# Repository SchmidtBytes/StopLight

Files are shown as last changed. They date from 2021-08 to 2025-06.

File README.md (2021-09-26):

# StopLight

This project is a 3D-printable stop light intended as build state indicator.

## 3D model

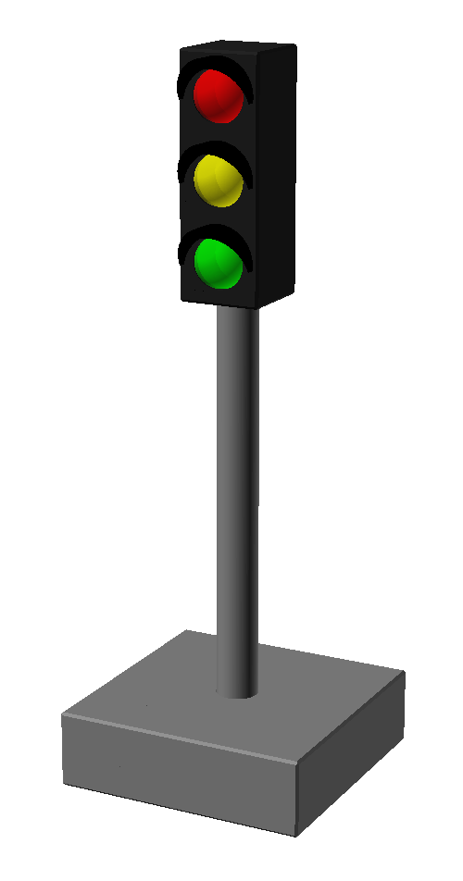
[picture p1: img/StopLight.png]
stop light


The model is created with [OpenSCAD](https://openscad.org/) and is made in a parametric way.

The following model parameters can easily be changed:
- Amount of LEDs
- En/Disable the sun shades above the LEDs
- The inner diameter of the pole for running cables
- The length of the pole
- Making the pole an independent object (allows to print in a different orientation for more stability)

There are also parameters to hide and enable certain parts of the model to simplify the export process.

Additionally there are some visualization tools:
- Show the LEDs in the model
- Show the Arduino Nano
- A cross section of the entire model to view the internal setup

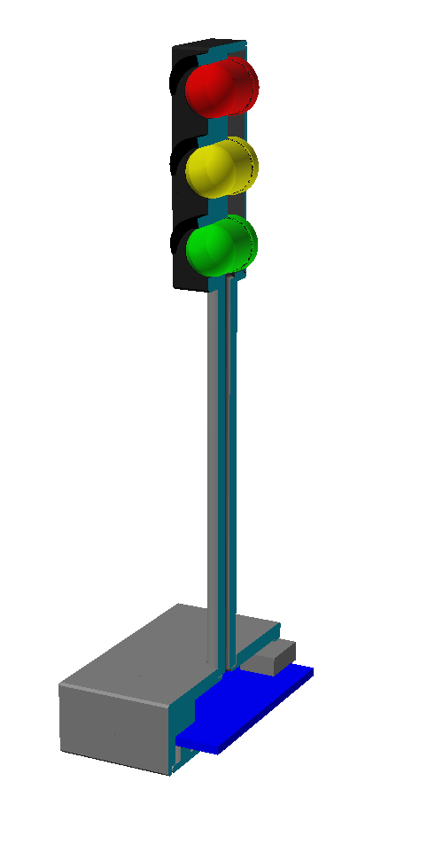
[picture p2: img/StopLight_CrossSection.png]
stop light cross section


## Bill of materials

These things are needed in order to assemble one of these stop lights
- [Arduino Nano](https://store.arduino.cc/products/arduino-nano) or a compatible board as the main brain of the stop lights
- LEDs with 10mm diameter (3 by default in red, yellow and green)
- One 180 Ohms resistor for each of the LEDs

Depending on where you buy these things this will run you about 5 to 20 € for the 3 LED variant.

Additionally you will need a soldering station, solder, some thin wires (preferably thread wire) and the material to 3D print the model.

## Assembly

At first you need to print all the parts for your stop light.

Then start with super gluing the pole to the housing and the base of the stop light.

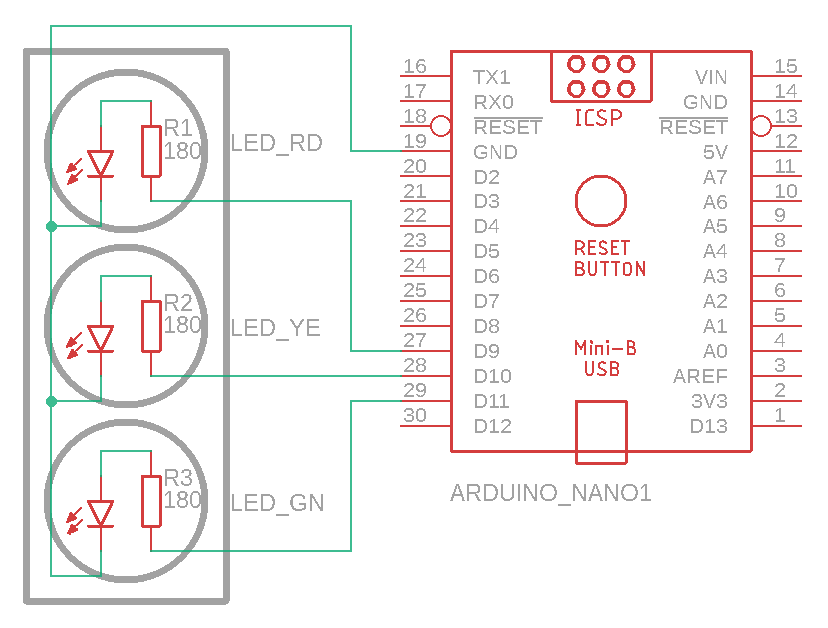
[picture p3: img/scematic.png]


Then add the LEDs from top to bottom. Keep all the cathodes on one side, so you can simply solder them all together and only need a single ground wire from the top to the base. The resistors are best added to the anode pin of the LEDs.

Once all the LEDs are wired and the connected to the Arduino Nano test them once before gluing them in place with super glue and then add the back panel of the stop light.
Then put the Arduino in the base and close the door.

## Software

This section gives insights about the default [StopLight_3](https://github.com/SchmidtBytes/StopLight/blob/main/programs/StopLight_3/StopLight_3.ino) program.
Other programs might add or delete features.

The programs are all written using the [Arduino IDE](https://www.arduino.cc/en/Main/Software_).

### LED usage

The LEDs are connected to the PWM pins of the Arduino so they can be used as digital and analog outputs.
They are wired in a way so that HIGH is LED on and LOW is LED off.

You can either write a digital value by using the digitalWrite command.

```c
digitalWrite(LED_RD, HIGH); // Turn the red LED on
digitalWrite(LED_GN, LOW);  // Turn the green LED off
```

Or you can also use the analogWrite command and set a value between 0 and 255.

```c
analogWrite(LED_YE, 127); // Set the yellow LED to half brightness
```

### Serial interface

The serial interface is connected via the USB port.
By default the baud rate is set to **38400**.
The Arduino will cyclically check for new commands on the serial interface and adapt its internal state machine.

### Commands

The commands are currently one letter codes for the various states.
The state will change if the code is known and the requested state is not already active.

| code | state | description |
|-----:|:---:|:---|
| i | STATE_INIT | Initialization animation |
| o | STATE_OFF | Turn off all of the LEDs |
| b | STATE_BUILDING  | Flash the yellow LED, but dim the transitions |
| s | STATE_SUCCESS | Light up only the green LED |
| u | STATE_UNSTABLE  | Light up only the yellow LED |
| f | STATE_FAILED | Light up only the red LED |
| p | STATE_PREPARE | Light up both yellow and red |
| n | STATE_NIGHT | Flash the yellow light, but with no dimming |
| w | STATE_WAIT | Flash the red and green LEDs at the same time |
| a | STATE_ALTERNATE | Alternate between yellow and the other LEDs |
| r | STATE_ROLLING | Rolling animation from red to green |
| c | STATE_CYCLE | Run a normal stop light animation |
| e | | Enable the sleep mode feature. This will be saved over power cycles  |
| d | | Disable the sleep mode feature. This will be saved over power cycles |

The stop light will accept the state codes both in upper and lower case letters.

### Sleep mode

Sleep mode is a feature to turn off the stop light LEDs after a certain amount of time has passed.
After this the stop light will automatically switch to **STATE_OFF**, but will continue to listen for commands.
By default this is set to 1 hour after receiving the last command.

### Libraries

As of now no external libraries are needed.

## Usage

The usage of the stop light is rather simple.
All typical operating systems come with the necessary drivers.
First you need to set the right baud rate to the serial interface (38400 by default).
In order to set the state just write the letter for the desired state to the serial interface.

From the Linux shell you can simply set the state with this command:

``` shell
echo s > /dev/ttyUSB0
```

## Contribution

Feel free to share and upload your own ideas and features.

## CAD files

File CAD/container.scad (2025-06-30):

use <StopLight.scad>

MATERIAL_THICKNESS = 1;
TOTAL_HEIGHT = 139;
MARGIN = .7;
BEND_LENGTH = (MARGIN + (MATERIAL_THICKNESS/2)) * PI/2;
echo("Bend length:", BEND_LENGTH);

/* [Global resolution] */
// Minimal facet size
$fs = 0.1;  // [0.1:0.01:10]
// Minimal angle size
$fa = 1;    // [1:0.1:90]

rotate([-90,0,0])translate([0,-25,95-(TOTAL_HEIGHT/2)])union() {
    housing(shades=true, lights=3);
    housing_back(3);
    pole(80);
    base_door();
}

//#translate([0,0,25])cube([50,TOTAL_HEIGHT,50],center=true);

translate([0,0,-(MATERIAL_THICKNESS/2)-MARGIN])cube([50,TOTAL_HEIGHT+(4*MARGIN)+(2*MATERIAL_THICKNESS),MATERIAL_THICKNESS],center=true);

translate([25,0,0])rotate([-90,0,0])rotate_extrude(angle = 90)translate([MARGIN+(MATERIAL_THICKNESS/2),0])square([MATERIAL_THICKNESS,TOTAL_HEIGHT+2*MARGIN+MATERIAL_THICKNESS],center=true);
translate([-25,0,0])rotate([-90,0,180])rotate_extrude(angle = 90)translate([MARGIN+(MATERIAL_THICKNESS/2),0])square([MATERIAL_THICKNESS,TOTAL_HEIGHT+2*MARGIN+MATERIAL_THICKNESS],center=true);

translate([(MATERIAL_THICKNESS/2)+MARGIN+25,0,25])cube([MATERIAL_THICKNESS,TOTAL_HEIGHT+2*MARGIN+MATERIAL_THICKNESS,50],center=true);
translate([-25-(MATERIAL_THICKNESS/2)-MARGIN,0,25])cube([MATERIAL_THICKNESS,TOTAL_HEIGHT+2*MARGIN+MATERIAL_THICKNESS,50],center=true);

translate([0,(TOTAL_HEIGHT/2)+(2*MARGIN)+MATERIAL_THICKNESS,0])rotate([-90,0,90])rotate_extrude(angle = 90)translate([MARGIN+(MATERIAL_THICKNESS/2),0])square([MATERIAL_THICKNESS,50],center=true);
translate([0,-(TOTAL_HEIGHT/2)-(2*MARGIN)-MATERIAL_THICKNESS,0])rotate([-90,0,-90])rotate_extrude(angle = 90)translate([MARGIN+(MATERIAL_THICKNESS/2),0])square([MATERIAL_THICKNESS,50],center=true);

translate([0,(TOTAL_HEIGHT/2)+MARGIN+(MATERIAL_THICKNESS/2),24])cube([50,MATERIAL_THICKNESS,48],center=true);
translate([0,-(TOTAL_HEIGHT/2)-MARGIN-(MATERIAL_THICKNESS/2),24])cube([50,MATERIAL_THICKNESS,48],center=true);
translate([0,(TOTAL_HEIGHT/2)+(MARGIN*3)+(1.5*MATERIAL_THICKNESS),24])cube([50,MATERIAL_THICKNESS,48],center=true);
translate([0,-(TOTAL_HEIGHT/2)-(MARGIN*3)-(1.5*MATERIAL_THICKNESS),24])cube([50,MATERIAL_THICKNESS,48],center=true);

translate([0,(TOTAL_HEIGHT/2)+(2*MARGIN)+MATERIAL_THICKNESS,48])rotate([90,0,90])rotate_extrude(angle = 180)translate([MARGIN+(MATERIAL_THICKNESS/2),0])square([MATERIAL_THICKNESS,50],center=true);
translate([0,-(TOTAL_HEIGHT/2)-(2*MARGIN)-MATERIAL_THICKNESS,48])rotate([90,0,-90])rotate_extrude(angle = 180)translate([MARGIN+(MATERIAL_THICKNESS/2),0])square([MATERIAL_THICKNESS,50],center=true);

translate([13,(TOTAL_HEIGHT/2)+(2*MARGIN)+(MATERIAL_THICKNESS),24])cube([24,MATERIAL_THICKNESS,48],center=true);
translate([-13,(TOTAL_HEIGHT/2)+(2*MARGIN)+(MATERIAL_THICKNESS),24])cube([24,MATERIAL_THICKNESS,48],center=true);
translate([13,-(TOTAL_HEIGHT/2)-(2*MARGIN)-(MATERIAL_THICKNESS),24])cube([24,MATERIAL_THICKNESS,48],center=true);
translate([-13,-(TOTAL_HEIGHT/2)-(2*MARGIN)-(MATERIAL_THICKNESS),24])cube([24,MATERIAL_THICKNESS,48],center=true);

translate([25,(TOTAL_HEIGHT/2)+(MARGIN)+(MATERIAL_THICKNESS/2),24])rotate([0,0,0])rotate_extrude(angle = 90)translate([MARGIN+(MATERIAL_THICKNESS/2),0])square([MATERIAL_THICKNESS,48],center=true);
translate([-25,(TOTAL_HEIGHT/2)+(MARGIN)+(MATERIAL_THICKNESS/2),24])rotate([0,0,90])rotate_extrude(angle = 90)translate([MARGIN+(MATERIAL_THICKNESS/2),0])square([MATERIAL_THICKNESS,48],center=true);
translate([25,-(TOTAL_HEIGHT/2)-(MARGIN)-(MATERIAL_THICKNESS/2),24])rotate([0,0,-90])rotate_extrude(angle = 90)translate([MARGIN+(MATERIAL_THICKNESS/2),0])square([MATERIAL_THICKNESS,48],center=true);
translate([-25,-(TOTAL_HEIGHT/2)-(MARGIN)-(MATERIAL_THICKNESS/2),24])rotate([0,0,180])rotate_extrude(angle = 90)translate([MARGIN+(MATERIAL_THICKNESS/2),0])square([MATERIAL_THICKNESS,48],center=true);

translate([-25,0,50])rotate([-90,-90,180])rotate_extrude(angle = 90)translate([MARGIN+(MATERIAL_THICKNESS/2),0])square([MATERIAL_THICKNESS,TOTAL_HEIGHT+2*MARGIN+MATERIAL_THICKNESS],center=true);
translate([25+(MARGIN)+(MATERIAL_THICKNESS/2),0,50])rotate([-90,-90,0])rotate_extrude(angle = 90)translate([MARGIN+(MATERIAL_THICKNESS/2),0])square([MATERIAL_THICKNESS,TOTAL_HEIGHT+2*MARGIN+MATERIAL_THICKNESS],center=true);

translate([(MARGIN/2)+(MATERIAL_THICKNESS/4),0,50+(MATERIAL_THICKNESS/2)+MARGIN])cube([50+MARGIN+(MATERIAL_THICKNESS/2),TOTAL_HEIGHT+2*MARGIN+MATERIAL_THICKNESS,MATERIAL_THICKNESS],center=true);
intersection() {
    translate([(MATERIAL_THICKNESS)+(MARGIN*2)+25,0,25])cube([MATERIAL_THICKNESS,TOTAL_HEIGHT+2*MARGIN+MATERIAL_THICKNESS,50],center=true);
    hull(){
        translate([(MATERIAL_THICKNESS)+(MARGIN*2)+25,(TOTAL_HEIGHT/2)-20+MARGIN+(MATERIAL_THICKNESS/2),50])rotate([0,90,0])cylinder(r=20,h=2*MATERIAL_THICKNESS,center=true);
        translate([(MATERIAL_THICKNESS)+(MARGIN*2)+25,-(TOTAL_HEIGHT/2)+20-MARGIN-(MATERIAL_THICKNESS/2),50])rotate([0,90,0])cylinder(r=20,h=2*MATERIAL_THICKNESS,center=true);
        translate([(MATERIAL_THICKNESS)+(MARGIN*2)+25,0,20])rotate([0,90,0])cylinder(r=20,h=2*MATERIAL_THICKNESS,center=true);
    }
}

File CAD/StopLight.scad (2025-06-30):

/* [Customization] */
// Ammount of LEDs for the stop light
NUM_LIGHTS       = 3; // [20]
// Add or remove the sunshades
SHADES           = true;
// The length of the stop light pole
POLE_LENGTH      = 80; // [2:0.01:200]
// Make the pole a separate object
INDEPENDENT_POLE = true;
// The inner diameter of the pole
POLE_DI          = 2; // [0:0.01:8]
// The controller used in the stop light
VARIANT             = "Arduino Nano"; // ["Arduino Nano", "ESP32-C6 Supermini"]
// The locking mechanism attaching the base door to the base
BASE_LOCK           = "Clip"; // ["Clip", "Screw"]

/* [Enable/Disable parts] */
// Show the LED housing
ENABLE_LED_HOUSING = true;
// Show the back of the LED housing
ENABLE_BACK_PANEL  = true;
// Show the pole
ENABLE_POLE        = true;
// Show the pole base
ENABLE_BASE        = true;
// Show the base door
ENABLE_BASE_DOOR   = true;

/* [Cosmetic options] */
// Show the LEDs
SHOW_LEDs        = false;
// Show the Arduino
SHOW_CONTROLLER  = false;
// Show a cross section of the stop light
CROSS_SECTION    = false;
// The angle to cut the cross section at
CROSS_SECTION_ANGLE = 0; // [-90:45:90]

/* [Global resolution] */
// Minimal facet size
$fs = 0.1;  // [0.1:0.01:10]
// Minimal angle size
$fa = 1;    // [1:0.1:90]


if(SHOW_LEDs) {
    if(NUM_LIGHTS > 1)
        translate([0,0,6+(15*(NUM_LIGHTS-1))])LED("#ff000080");
    if(NUM_LIGHTS > 2) {
        for(i=[0:NUM_LIGHTS-3]) {
            translate([0,0,6+(15*(i+1))])LED("#ffff0080");
        }
    }
    translate([0,0,6])LED("#00ff0080");
}

if(SHOW_CONTROLLER && VARIANT == "Arduino Nano") {
    translate([0,1.75,-POLE_LENGTH-8.5])arduino_nano();
}
if(SHOW_CONTROLLER && VARIANT == "ESP32-C6 Supermini") {
    translate([0,11.8,-POLE_LENGTH-8.5])ESP32_C3_SuperMini();
}

difference() {
    union() {
        if(ENABLE_LED_HOUSING) {
            housing(shades=SHADES, lights=NUM_LIGHTS);
        }
        if(ENABLE_BACK_PANEL) {
            housing_back(lights=NUM_LIGHTS);
        }
        pole(POLE_LENGTH);
        if(ENABLE_BASE_DOOR) {
            base_door();
        }
    }
    if(CROSS_SECTION) {
        rotate([0,0,CROSS_SECTION_ANGLE])translate([0,-40,-POLE_LENGTH-30])cube([50,80,40+(15*NUM_LIGHTS)+POLE_LENGTH]);
    }
}

module LED(col="") {
    color(col) union() {
        translate([0,0.5,0])rotate([90,0,0])cylinder(d=10,h=7);
        rotate([-90,0,0])cylinder(d=11,h=2);
        translate([0,-6.5,0])sphere(d=10);
    }
}

module housing_back(lights = 3) {
    box_height = 16 + ((lights-1)*15);
    color("#404040")translate([0,7.5,(box_height/2)-2])
    slanted_cube(16-2.2,1,box_height-2.2);
    color("#404040")translate([0,7.75,(box_height/2)-2])
    cube([16-2.2,0.5,box_height-2.2],center=true);
}

module housing(shades=false,lights = 3) {
    box_height = 16 + ((lights-1)*15);
    color("#202020")translate([0,0,(box_height/2)-2])difference() {
        // main body
        slanted_cube(16,16,box_height);

        for(i=[0:lights-1]) {
            // LEDs
            translate([0,0,((15*(lights-1))/2)-(15*i)])rotate([90,0,0])linear_extrude(height=8.01,scale=0.95)circle(d=10.6);
            translate([0,-0.20,((15*(lights-1))/2)-(15*i)])rotate([-90,0,0])cylinder(d=12.5,h=10);
        }

        // remove interior
        translate([0,7.8,0])cube([10,16,box_height-6],center=true);
        translate([0,14.8,0])cube([14,16,box_height-2],center=true);

        // pole
        translate([0,0,(-box_height/2)+2])cylinder(d=2,h=5,center=true);
        translate([0,0,(-box_height/2)-1])cylinder(d=6.2,h=6,center=true);
    }

    // shields
    if(shades) {
        for(j=[0:lights-1]) {
            color("#000000")translate([0,0,(box_height/2)-2])difference () {
                translate([0,-7,((15*(lights-1))/2)-(15*j)+0.1])rotate([90,0,0])cylinder(d=14,h=6);
                translate([0,-6.5,((15*(lights-1))/2)-(15*j)-1.9])rotate([90,0,0])cylinder(d=14,h=7);
                translate([0,-10,((15*(lights-1))/2)-(15*j)])rotate([110,0,0])cylinder(d=17,h=7);
            }
        }
    }
}

module pole(length=70) {
    if(ENABLE_POLE) {
        color("gray")translate([0,0,-length/2])difference() {
            union() {
                cylinder(d=6,h=length,center=true);
                if(INDEPENDENT_POLE) {
                    translate([0,0,-2])cylinder(d=8,h=length,center=true);
                } else {
                    translate([0,0,-1])cylinder(d=8,h=length-2,center=true);
                }
            }
            cylinder(d=POLE_DI,h=length+10,center=true);
            translate([0,0,length/2])rotate([-90,0,0])cylinder(d=2,h=6);
        }
    }

    if(ENABLE_BASE){
        translate([0,0,-length])base();
    }
}

module base_door() {
    color("gray")translate([0,0,-15-POLE_LENGTH]) difference() {
        union() {
            difference() {
                union() {
                    translate([0,0,0.75])slanted_cube(46.6,46.6,1.5);
                    if(BASE_LOCK == "Clip") {
                        translate([-20,0,4])rotate([90,0,0])cylinder(d=3.6, h=20,center=true);
                    }
                    if(BASE_LOCK == "Screw") {
                        translate([-17,0,2.5])cylinder(d1=10.8,d2=8.8,h=2,center=true);
                    }
                }
                if(BASE_LOCK == "Clip") {
                    translate([-21.5,0,0.9])cube([15,22,2],center=true);
                    translate([-17,0,0.9])cube([4,21,10],center=true);
                }
                if(BASE_LOCK == "Screw") {
                    translate([-17,0,-2])cylinder(d=3.2,h=15,center=true);
                    translate([-17,0,.99])cylinder(d2=3.2,d1=6.4,h=2,center=true);
                }
            }
            if(BASE_LOCK == "Clip") {
                translate([-8,0,0]) difference() {
                    rotate([90,0,0])cylinder(d=26, h=20,center=true);
                    rotate([90,0,0])cylinder(d=22, h=21,center=true);
                    translate([0,0,-10])cube([50,50,20],center=true);
                    translate([21,0,8])cube([50,50,20],center=true);
                }
                translate([-13,0,5.5])cube([2,20,11],center=true);
            }
            translate([15.8,-10,5])rotate([90,0,0])linear_extrude(height=10)polygon([[0,-5],[5,1],[7,1],[7,-0.3],[5,-0.8],[5,-5]]);
            translate([15.8,20,5])rotate([90,0,0])linear_extrude(height=10)polygon([[0,-5],[5,1],[7,1],[7,-0.3],[5,-0.8],[5,-5]]);
            if(BASE_LOCK == "Clip") {
                translate([0,-18,0])cylinder(d=4,h=5.4);
            }
            if(BASE_LOCK == "Screw") {
                translate([-7,2,0])cylinder(d=4,h=5.95);
                translate([7,2,0])cylinder(d=4,h=5.95);
            }
        }
        if(BASE_LOCK == "Clip") {
            translate([-11.5,0,12])rotate([0,45,0])cube([3,22,3],center=true);
        }
    }
}

module base() {
    color("gray")translate([0,0,-7.5])difference() {
        slanted_cube(50,50,15);
        translate([0,0,3.8])linear_extrude(height=6,scale=0)circle(d=5);
        translate([0,0,-13.3])cube([47,47,15],center=true);
        translate([0,0,-5+2])cube([20,44,15],center=true);
        translate([16,0,-5+4])cube([10,44,15],center=true);
        translate([18,0,-5+4+2.5])cube([10,44,10],center=true);
        if(BASE_LOCK == "Clip") {
            translate([-16,0,-5+4])cube([10,44,15],center=true);
            translate([-20,0,-6.5+3])rotate([90,0,0])cylinder(d=4, h=22,center=true);
        }
        else if(BASE_LOCK == "Screw") {
            translate([-17,0,-2])cylinder(d=4.1,h=15,center=true);
            translate([-17,0,-4.81])cylinder(d1=11,d2=9,h=2,center=true);
        }
        cylinder(d=POLE_DI, h=16);
        if(INDEPENDENT_POLE) {
            translate([0,0,5.3])cylinder(d=8.3, h=16);
        }
        if(VARIANT == "Arduino Nano") {
            translate([0,1.75,-10.5+7.5+2])arduino_nano();
        }
        else if(VARIANT == "ESP32-C6 Supermini") {
            translate([0,11.8,-10.5+7.5+2])ESP32_C3_SuperMini();
        }
    }
    if(VARIANT == "Arduino Nano") {
        color("gray")difference() {
            translate([0,-19,-5])cube([10,10,8],center=true);
            translate([0,1.75,-10.5+2])arduino_nano();
        }
    }
    else if(VARIANT == "ESP32-C6 Supermini") {
        color("gray")difference() {
            union() {
                translate([-10,0,-9])cylinder(d=5, h=8);
                translate([10,0,-9])cylinder(d=5, h=8);
            }
            translate([0,11.8,-10.5+2])ESP32_C3_SuperMini();
            translate([13.5,0,-6])cube([6,6,10],center=true);
        }
    }
}

module ESP32_C3_SuperMini() {
    color("blue")translate([0,-.25,0])cube([18.3,23.2,1.1],center=true);
    color("#404040")translate([0,5.75,1.1/2])rotate([-90,0,0])hull() {
        translate([(8.9-3.1)/2,-3.1/2,0])cylinder(d=3.4, h=7.5);
        translate([-(8.9-3.1)/2,-3.1/2,0])cylinder(d=3.4, h=7.5);
    }
    color("#202020")translate([-5.8,10,2.1/2])cube([2.75,3,1],center=true);
}
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

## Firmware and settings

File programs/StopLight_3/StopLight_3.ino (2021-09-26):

/*
  Build status stop light code
  V 1.0
*/

#include <EEPROM.h>

// LED Pin definitions
#define LED_RD 9
#define LED_YE 10
#define LED_GN 11

// Serial speed definition
#define SERIAL_SPEED 38400

// Non state commands:
// code: e; Enables the sleep mode feature (default: enabled)
//          WARNING this setting will be persisted and will not reset when turning the device off
// code: d; Disables the sleep mode feature (default: enabled)
//          WARNING this setting will be persisted and will not reset when turning the device off

// stop light state definitions
#define STATE_INIT       0 // code: i; Initialization animation
#define STATE_OFF        1 // code: o; Turn off all of the LEDs
#define STATE_BUILDING   2 // code: b; Flash the yellow LED, but dim the transitions
#define STATE_SUCCESS    3 // code: s; Light up only the green LED
#define STATE_UNSTABLE   4 // code: u; Light up only the yellow LED
#define STATE_FAILED     5 // code: f; Light up only the red LED
#define STATE_PREPARE    6 // code: p; Light up both yellow and red
#define STATE_NIGHT      7 // code: n; Flash the yellow light, but with no dimming
#define STATE_WAIT       8 // code: w; Flash the red and green LEDs at the same time
#define STATE_ALTERNATE  9 // code: a; Alternate between yellow and the other LEDs
#define STATE_ROLLING   10 // code: r; Rolling animation from red to green
#define STATE_CYCLE     98 // code: c; Run a normal stop light animation
#define STATE_PARTY     99 // code: $; Flash the LEDs at random times and brightness levels

// Timing
#define CYCLE_TIME      10 // [ms] Time to wait in between cycles
#define TURN_OFF_TIME   ((uint32_t) 3600/*[s/h]*/ * 1000/*[ms/s]*/ / CYCLE_TIME/*[ms/cycle]*/)
                        // Number of cycles before turning the stop light off
                        // (default: Turn off after 1 hour)

#define SLEEP_STATE_ADDR 0x000 // Location of the sleep state in the EEPROM that is read on start

int incoming_byte = 0;                  // for incoming serial data
int state = 0;                          // memory for the currently active state
bool sleep_active = true;               // Holds the current state if sleep mode is active
uint32_t sleep_timer = TURN_OFF_TIME;   // counter to enable sleep mode
unsigned long next_cycle = CYCLE_TIME;  // time when to start with the next cycle
unsigned long time_mili = 0;            // Current system time in miliseconds
int state_var = 0;                      // variable that can be used by the currently active state to save some information
                                        // This is mostly used to time the flash patterns for repeating states
uint32_t change_time_r = TURN_OFF_TIME; // Variable to save when to change the red LED; only used in some states
uint32_t change_time_y = TURN_OFF_TIME; // Variable to save when to change the yellow LED; only used in some states
uint32_t change_time_g = TURN_OFF_TIME; // Variable to save when to change the green LED; only used in some states

// the setup function runs once when you press reset or power the board
void setup() {
  // initialize the serial interface
  Serial.begin(SERIAL_SPEED);

  // setup the pins of the leds
  pinMode(LED_RD, OUTPUT);
  pinMode(LED_YE, OUTPUT);
  pinMode(LED_GN, OUTPUT);

  // read from an unconnected analog input to initialize the random function
  randomSeed(analogRead(0));

  // initialize sleep_active from EEPROM
  incoming_byte = EEPROM.read(SLEEP_STATE_ADDR);
  if(incoming_byte > 1) {
    // Initialize the EEPROM with true if the value is not valid
    EEPROM.write(SLEEP_STATE_ADDR, true);
    incoming_byte = 1;
  }
  sleep_active = incoming_byte;
}

// the loop function runs over and over again forever
void loop() {
  if (Serial.available() > 0) {
    // read a byte from the serial interface
    incoming_byte = Serial.read();
    // convert to lower case
    if (incoming_byte >= 'A' && incoming_byte <= 'Z')
        incoming_byte += 'a' - 'A';

    bool byte_accepted = true;
    // Check none state commands
    if(incoming_byte == 'd'){
        sleep_active = false;
        EEPROM.write(SLEEP_STATE_ADDR, sleep_active);
        digitalWrite(LED_YE, LOW);
        digitalWrite(LED_GN, LOW);
        for(uint8_t ctr = 0; ctr < 8; ctr++) {
            digitalWrite(LED_RD, (ctr + 1)%2);
            delay(125);
        }
    }
    else if(incoming_byte == 'e') {
        sleep_active = true;
        EEPROM.write(SLEEP_STATE_ADDR, sleep_active);
        digitalWrite(LED_RD, LOW);
        digitalWrite(LED_YE, LOW);
        for(uint8_t ctr = 0; ctr < 8; ctr++) {
            digitalWrite(LED_GN, (ctr + 1)%2);
            delay(125);
        }
    }

    // Check which state was requested and set it up if necessary
    if(incoming_byte == 'i' && state != STATE_INIT)
      state = STATE_INIT;
    else if(incoming_byte == 'o' && state != STATE_OFF)
      state = STATE_OFF;
    else if(incoming_byte == 'b' && state != STATE_BUILDING)
      state = STATE_BUILDING;
    else if(incoming_byte == 's' && state != STATE_SUCCESS)
      state = STATE_SUCCESS;
    else if(incoming_byte == 'u' && state != STATE_UNSTABLE)
      state = STATE_UNSTABLE;
    else if(incoming_byte == 'f' && state != STATE_FAILED)
      state = STATE_FAILED;
    else if(incoming_byte == 'p' && state != STATE_PREPARE)
      state = STATE_PREPARE;
    else if(incoming_byte == 'n' && state != STATE_NIGHT)
      state = STATE_NIGHT;
    else if(incoming_byte == 'w' && state != STATE_WAIT)
      state = STATE_WAIT;
    else if(incoming_byte == 'a' && state != STATE_ALTERNATE)
      state = STATE_ALTERNATE;
    else if(incoming_byte == 'r' && state != STATE_ROLLING)
      state = STATE_ROLLING;
    else if(incoming_byte == 'c' && state != STATE_CYCLE)
      state = STATE_CYCLE;
    else if(incoming_byte == '$' && state != STATE_PARTY)
    {
      state = STATE_PARTY;
      change_time_r = TURN_OFF_TIME;
      change_time_y = TURN_OFF_TIME;
      change_time_g = TURN_OFF_TIME;
    }
    else
      // detect if requested state is already active or state code was invalid
      byte_accepted = false;

    if(byte_accepted)
        // Reset the state var for the new state
        state_var=0;
    else if(state == STATE_PARTY)
    {
        uint32_t diff_time = TURN_OFF_TIME - sleep_timer;
        change_time_r += diff_time;
        change_time_y += diff_time;
        change_time_g += diff_time;
    }

    // reset the sleep timer
    sleep_timer = TURN_OFF_TIME;
  }

  // State machine for the various states
  switch(state){
    case STATE_INIT:
      if (state_var < (500/*ms*/ / CYCLE_TIME)) {
        analogWrite(LED_RD, (255 * (state_var % (500/*ms*/ / CYCLE_TIME))) / (500/*ms*/ / CYCLE_TIME));
        digitalWrite(LED_YE, LOW);
        digitalWrite(LED_GN, LOW);
      }
      else if(state_var < (1000/*ms*/ / CYCLE_TIME)) {
        digitalWrite(LED_RD, HIGH);
        analogWrite(LED_YE, (255 * (state_var % (500/*ms*/ / CYCLE_TIME))) / (500/*ms*/ / CYCLE_TIME));
        digitalWrite(LED_GN, LOW);
      }
      else if(state_var < (1500/*ms*/ / CYCLE_TIME)) {
        digitalWrite(LED_RD, HIGH);
        digitalWrite(LED_YE, HIGH);
        analogWrite(LED_GN, (255 * (state_var % (500/*ms*/ / CYCLE_TIME))) / (500/*ms*/ / CYCLE_TIME));
      }
      else if(state_var < (3000/*ms*/ / CYCLE_TIME)) {
        digitalWrite(LED_RD, HIGH);
        digitalWrite(LED_YE, HIGH);
        digitalWrite(LED_GN, HIGH);
      }
      else if(state_var < (3500/*ms*/ / CYCLE_TIME)) {
        analogWrite(LED_RD, 255 - ((255 * (state_var % (500/*ms*/ / CYCLE_TIME))) / (500/*ms*/ / CYCLE_TIME)));
        digitalWrite(LED_YE, HIGH);
        digitalWrite(LED_GN, HIGH);
      }
      else if(state_var < (4000/*ms*/ / CYCLE_TIME)) {
        digitalWrite(LED_RD, LOW);
        analogWrite(LED_YE, 255 - ((255 * (state_var % (500/*ms*/ / CYCLE_TIME))) / (500/*ms*/ / CYCLE_TIME)));
        digitalWrite(LED_GN, HIGH);
      }
      else if(state_var < (4500/*ms*/ / CYCLE_TIME)) {
        digitalWrite(LED_RD, LOW);
        digitalWrite(LED_YE, LOW);
        analogWrite(LED_GN, 255 - ((255 * (state_var % (500/*ms*/ / CYCLE_TIME))) / (500/*ms*/ / CYCLE_TIME)));
      }
      else {
        // Automatically switch to off state after finishing the initialization animation
        state = STATE_OFF;
        sleep_timer = 0;
      }
      // increase the state var to run through the animation
      state_var ++;
      break;

    case STATE_OFF:
      digitalWrite(LED_RD, LOW);
      digitalWrite(LED_YE, LOW);
      digitalWrite(LED_GN, LOW);
      break;

    case STATE_BUILDING:
      digitalWrite(LED_RD, LOW);
      if(state_var < (500/*ms*/ / CYCLE_TIME))
        analogWrite(LED_YE, (255 * state_var) / (500/*ms*/ / CYCLE_TIME));
      else if(state_var < (750/*ms*/ / CYCLE_TIME))
      {
        digitalWrite(LED_YE, HIGH);
      }
      else if(state_var < (1250/*ms*/ / CYCLE_TIME))
        analogWrite(LED_YE, 255 - ((255 * (state_var - (750 / CYCLE_TIME))) / (500/*ms*/ / CYCLE_TIME)));
      else
        digitalWrite(LED_YE, LOW);
      digitalWrite(LED_GN, LOW);
      // increase the state_var to run through the animation
      state_var = (state_var + 1) % (1500/*ms*/ / CYCLE_TIME);
      break;

    case STATE_SUCCESS:
      digitalWrite(LED_RD, LOW);
      digitalWrite(LED_YE, LOW);
      digitalWrite(LED_GN, HIGH);
      break;

    case STATE_UNSTABLE:
      digitalWrite(LED_RD, LOW);
      digitalWrite(LED_YE, HIGH);
      digitalWrite(LED_GN, LOW);
      break;

    case STATE_FAILED:
      digitalWrite(LED_RD, HIGH);
      digitalWrite(LED_YE, LOW);
      digitalWrite(LED_GN, LOW);
      break;

    case STATE_PREPARE:
      digitalWrite(LED_RD, HIGH);
      digitalWrite(LED_YE, HIGH);
      digitalWrite(LED_GN, LOW);
      break;

    case STATE_NIGHT:
      digitalWrite(LED_RD, LOW);
      digitalWrite(LED_YE, state_var<(1000/*ms*/ / CYCLE_TIME)?HIGH:LOW);
      digitalWrite(LED_GN, LOW);
      // increase the state_var to run through the animation
      state_var = (state_var + 1) % (2000/*ms*/ / CYCLE_TIME);
      break;

    case STATE_WAIT:
      digitalWrite(LED_RD, state_var<(500/*ms*/ / CYCLE_TIME)?HIGH:LOW);
      digitalWrite(LED_YE, LOW);
      digitalWrite(LED_GN, state_var<(500/*ms*/ / CYCLE_TIME)?HIGH:LOW);
      // increase the state_var to run through the animation
      state_var = (state_var + 1) % (1000/*ms*/ / CYCLE_TIME);
      break;

    case STATE_ALTERNATE:
      digitalWrite(LED_RD, state_var<(1000/*ms*/ / CYCLE_TIME)?HIGH:LOW);
      digitalWrite(LED_YE, state_var<(1000/*ms*/ / CYCLE_TIME)?LOW:HIGH);
      digitalWrite(LED_GN, state_var<(1000/*ms*/ / CYCLE_TIME)?HIGH:LOW);
      // increase the state_var to run through the animation
      state_var = (state_var + 1) % (2000/*ms*/ / CYCLE_TIME);
      break;

    case STATE_ROLLING:
      if (state_var < (500/*ms*/ / CYCLE_TIME)) {
        analogWrite(LED_RD, (255 * state_var) / (500/*ms*/ / CYCLE_TIME));
        digitalWrite(LED_YE, LOW);
        digitalWrite(LED_GN, LOW);        
      }
      else if (state_var < (1000/*ms*/ / CYCLE_TIME)) {
        analogWrite(LED_RD, 255 - ((255 * (state_var - (500 / CYCLE_TIME))) / (500/*ms*/ / CYCLE_TIME)));
        analogWrite(LED_YE, (255 * (state_var - (500 / CYCLE_TIME))) / (500/*ms*/ / CYCLE_TIME));
        digitalWrite(LED_GN, LOW);
      }
      else if (state_var < (1500/*ms*/ / CYCLE_TIME)) {
        digitalWrite(LED_RD, LOW);
        analogWrite(LED_YE, 255 - ((255 * (state_var - (1000 / CYCLE_TIME))) / (500/*ms*/ / CYCLE_TIME)));
        analogWrite(LED_GN, (255 * (state_var - (1000 / CYCLE_TIME))) / (500/*ms*/ / CYCLE_TIME));
      }
      else if (state_var < (2000/*ms*/ / CYCLE_TIME)) {
        digitalWrite(LED_RD, LOW);
        digitalWrite(LED_YE, LOW);
        analogWrite(LED_GN, 255 - ((255 * (state_var - (1500 / CYCLE_TIME))) / (500/*ms*/ / CYCLE_TIME)));
      }
      else {
        digitalWrite(LED_RD, LOW);
        digitalWrite(LED_YE, LOW);
        digitalWrite(LED_GN, LOW);
      }
      // increase the state_var to run through the animation
      state_var = (state_var + 1) % (3000/*ms*/ / CYCLE_TIME);
      break;

    case STATE_CYCLE:
      if(state_var < (10000/*ms*/ / CYCLE_TIME)) {
        digitalWrite(LED_RD, HIGH);
        digitalWrite(LED_YE, LOW);
        digitalWrite(LED_GN, LOW);
      }
      else if(state_var < (11000/*ms*/ / CYCLE_TIME))
        digitalWrite(LED_YE, HIGH);
      else if(state_var < (21000/*ms*/ / CYCLE_TIME)) {
        digitalWrite(LED_RD, LOW);
        digitalWrite(LED_YE, LOW);
        digitalWrite(LED_GN, HIGH);
      }
      else {
        digitalWrite(LED_YE, HIGH);
        digitalWrite(LED_GN, LOW);
      }
      // increase the state_var to run through the animation
      state_var = (state_var + 1) % (23000/*ms*/ / CYCLE_TIME);
      break;

    case STATE_PARTY:
      // randomize the brightness levels and change times for all LEDs independently
      if (change_time_r >= sleep_timer)
      {
        analogWrite(LED_RD, random(6)* 51);
        change_time_r = sleep_timer - random(25, 150);
      }
      if (change_time_y >= sleep_timer)
      {
        analogWrite(LED_YE, random(6)* 51);
        change_time_y = sleep_timer - random(25, 150);
      }
      if (change_time_g >= sleep_timer)
      {
        analogWrite(LED_GN, random(6)* 51);
        change_time_g = sleep_timer - random(25, 150);
      }
      break;

    default:
      // reinitialize when the current state is invalid
      state = STATE_INIT;
      break;
  }

  if(sleep_timer > 0)
    // count down the time when to turn the stop light off
    sleep_timer--;
  if(sleep_timer == 0) {
    if(sleep_active)
      // switch to state off after the sleep_timer ran out and sleep is active
      state = STATE_OFF;
    else
      // reset the sleep timer and the rgb change times
      change_time_r = change_time_y = change_time_g = sleep_timer = TURN_OFF_TIME;
  }

  // Wait some time before starting the next cycle
  do {
    time_mili = millis();
  } while(time_mili <= next_cycle || (next_cycle > ((unsigned long)100 * CYCLE_TIME) && (time_mili < ((unsigned long) 90 * CYCLE_TIME))));
  do {
    next_cycle += CYCLE_TIME;
  }while(next_cycle < time_mili && next_cycle >= CYCLE_TIME);
}

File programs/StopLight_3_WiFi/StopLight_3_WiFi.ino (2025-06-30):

/*
  Build status stop light code - Wifi
  V 2.0

  This program can set the stop light from eiter serial commands or a web page.
  This program was initially developed for a MakerGO ESP32 C6 SuperMini

  For the web page this supports Access Point and Client modes in parallel.
  You can trigger state switches via get request and there is a JSON API on the /state subpage.
  The subpage links for states and actions are the same as the serial codes

  For serial controls there are different messages for the states as well as actions.
  States:
  code: i; Initialization animation
  code: o; Turn off all of the LEDs
  code: b; Flash the yellow LED, but dim the transitions
  code: s; Light up only the green LED
  code: u; Light up only the yellow LED
  code: f; Light up only the red LED
  code: p; Light up both yellow and red
  code: n; Flash the yellow light, but with no dimming
  code: w; Flash the red and green LEDs at the same time
  code: a; Alternate between yellow and the other LEDs
  code: r; Rolling animation from red to green
  code: c; Run a normal stop light animation
  code: $; Flash the LEDs at random times and brightness levels
  Actions:
  code: e; Enables the sleep mode feature to turn the light off after 1 hour. This is persisted to the EEPROM.
  code: d; Disables the sleep mode feature to turn the light off after 1 hour. This is persisted to the EEPROM.
 */

#include <WiFi.h>
#include <EEPROM.h>
#include "state_machine.h"
#include "pins.h"
#include "wifi_config.h"
#include "wifi_msg.h"

// Serial speed definition
#define SERIAL_SPEED 38400

#define SLEEP_STATE_ADDR 0x000 // Location of the sleep state in the EEPROM that is read on start

int incoming_byte = 0;         // for incoming serial data
NetworkServer server(80);      // Webserver for WiFi controls

void setup()
{
  // initialize the serial interface
  Serial.begin(SERIAL_SPEED);

  // setup the pins of the leds
  pinMode(LED_RD, OUTPUT);
  pinMode(LED_YE, OUTPUT);
  pinMode(LED_GN, OUTPUT);

  // read from an unconnected analog input to initialize the random function
  randomSeed(analogRead(0));

  // Initialize EEPROM
  if (!EEPROM.begin(16)) {
    Serial.println("failed to initialize EEPROM");
    analogWrite(LED_RD, 255);
    analogWrite(LED_YE, 255);
    analogWrite(LED_GN, 255);
    active_state = STATE_OFF;
    delay(5000);
  }
  // initialize sleep_active from EEPROM
  incoming_byte = EEPROM.read(SLEEP_STATE_ADDR);
  if(incoming_byte > 1) {
    // Initialize the EEPROM with true if the value is not valid
    EEPROM.write(SLEEP_STATE_ADDR, true);
    EEPROM.commit();
    incoming_byte = 1;
  }
  sleep_active = incoming_byte;

  delay(10);
  Serial.println("############################################################");

  // Set up the WiFi Access Point if it is configured
#ifdef WIFI_ENABLE_AP
  Serial.println();
  Serial.println("Configuring access point...");

  WiFi.AP.begin();
  WiFi.AP.config(ap_ip, ap_ip, ap_mask, ap_leaseStart, ap_dns);
  WiFi.AP.create(ssid_ap, password_ap);
  if (!WiFi.AP.waitStatusBits(ESP_NETIF_STARTED_BIT, 1000)) {
    Serial.println("Failed to start AP!");
    return;
  }
  Serial.print("AP IP address: ");
  Serial.println(ap_ip);
#endif

  // Connect to a WiFi network if configured
#ifdef WIFI_ENABLE_CLIENT
  Serial.println();
  Serial.print("Connecting to ");
  Serial.println(ssid);

  WiFi.begin(ssid, password);

  while (WiFi.status() != WL_CONNECTED) {
    delay(500);
    Serial.print(".");
  }

  Serial.println("");
  Serial.println("WiFi connected.");
  Serial.println("IP address: ");
  Serial.println(WiFi.localIP());
#endif

  // Start the Webserver
  Serial.println();
  server.begin();
  Serial.println("Server started");
  Serial.println();
  Serial.flush();
  Serial.readString(); // Clear read buffer
}

void loop() {
  NetworkClient client = server.accept();  // listen for incoming clients

  if (client) {                     // if you get a client,
    Serial.println("New Client.");  // print a message out the serial port
    String currentLine = "";        // make a String to hold incoming data from the client
    String requested_page = "";
    uint8_t message_type = MSG_ERROR; // Enables error banner on response page
    while (client.connected()) {    // loop while the client's connected
      if (client.available()) {     // if there's bytes to read from the client,
        char c = client.read();     // read a byte, then
        Serial.write(c);            // print it out the serial monitor
        if (c == '\n') {            // if the byte is a newline character

          // if the current line is blank, you got two newline characters in a row.
          // that's the end of the client HTTP request, so send a response:
          if (currentLine.length() == 0) {
            if (requested_page.equals("state")) {
              // Send JSON response when state page is requested
              send_json_status(client);
            }
            else {
              // Send HTML response for all other requests
              send_html_response(client, requested_page, message_type);
            }
            // break out of the while loop:
            break;
          } else {  // if you got a newline, then clear currentLine:
            // Only process the get line from the request
            if (currentLine.startsWith("GET /")) {
              // Ignore initial part of the get request and remove everything after the first space in the string
              requested_page = currentLine.substring(5);
              int space_idx = requested_page.indexOf(' ');
              if (space_idx >= 0) {
                requested_page = requested_page.substring(0,space_idx);
              }
              // Convert all requests to lower page
              requested_page.toLowerCase();
              Serial.print("    Requested Page: '");
              Serial.print(requested_page);
              Serial.println("'");
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

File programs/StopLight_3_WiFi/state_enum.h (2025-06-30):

#ifndef STOP_LIGHT_STATE_ENUM_H
#define STOP_LIGHT_STATE_ENUM_H

#include <stdint.h>
#include <map>
#include <SPIFFS.h>

// Enum for the stop light state
enum StopLightState : uint8_t {
    STATE_INIT      =   0, // code: i; Initialization animation
    STATE_OFF       =   1, // code: o; Turn off all of the LEDs
    STATE_BUILDING  =   2, // code: b; Flash the yellow LED, but dim the transitions
    STATE_SUCCESS   =   3, // code: s; Light up only the green LED
    STATE_UNSTABLE  =   4, // code: u; Light up only the yellow LED
    STATE_FAILED    =   5, // code: f; Light up only the red LED
    STATE_PREPARE   =   6, // code: p; Light up both yellow and red
    STATE_NIGHT     =   7, // code: n; Flash the yellow light, but with no dimming
    STATE_WAIT      =   8, // code: w; Flash the red and green LEDs at the same time
    STATE_ALTERNATE =   9, // code: a; Alternate between yellow and the other LEDs
    STATE_ROLLING   =  10, // code: r; Rolling animation from red to green
    STATE_CYCLE     =  98, // code: c; Run a normal stop light animation
    STATE_PARTY     =  99, // code: $; Flash the LEDs at random times and brightness levels

    STATE_UNKNOWN   = 255  // State used for invalid states.
};

// Map to convert the StopLightState into the command chars
const static std::map<StopLightState,char> STATE_CHAR_MAP = {
    {STATE_INIT,      'i'},
    {STATE_OFF,       'o'},
    {STATE_BUILDING,  'b'},
    {STATE_SUCCESS,   's'},
    {STATE_UNSTABLE,  'u'},
    {STATE_FAILED,    'f'},
    {STATE_PREPARE,   'p'},
    {STATE_NIGHT,     'n'},
    {STATE_WAIT,      'w'},
    {STATE_ALTERNATE, 'a'},
    {STATE_ROLLING,   'r'},
    {STATE_CYCLE,     'c'},
    {STATE_PARTY,     '$'},
    {STATE_UNKNOWN,   'X'}
};

// Map to convert the command chars into a StopLightState
const static std::map<char,StopLightState> CHAR_STATE_MAP = {
    {'i', STATE_INIT},
    {'o', STATE_OFF},
    {'b', STATE_BUILDING},
    {'s', STATE_SUCCESS},
    {'u', STATE_UNSTABLE},
    {'f', STATE_FAILED},
    {'p', STATE_PREPARE},
    {'n', STATE_NIGHT},
    {'w', STATE_WAIT},
    {'a', STATE_ALTERNATE},
    {'r', STATE_ROLLING},
    {'c', STATE_CYCLE},
    {'$', STATE_PARTY}
};

// Map to convert the StopLightState into a String
const static std::map<StopLightState,String> STATE_STRING_MAP = {
    {STATE_INIT,      "Init"},
    {STATE_OFF,       "OFF"},
    {STATE_BUILDING,  "Dimmed Mode"},
    {STATE_SUCCESS,   "Go"},
    {STATE_UNSTABLE,  "Hold"},
    {STATE_FAILED,    "Stop"},
    {STATE_PREPARE,   "Prepare"},
    {STATE_NIGHT,     "Night mode"},
    {STATE_WAIT,      "Wait"},
    {STATE_ALTERNATE, "Alternating"},
    {STATE_ROLLING,   "Rolling"},
    {STATE_CYCLE,     "Cycle"},
    {STATE_PARTY,     "Party"},
    {STATE_UNKNOWN,   "UNKNOWN_STATE"}
};

#endif // STOP_LIGHT_STATE_ENUM_H

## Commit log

2021-08-26 Added initial project files
    Added 3d model
    Added Arduino code
    Updated readme file
    Added gitignore file
    [StopLight.scad]
2021-08-28 Fixed bug in TURN_OFF_TIME calculation
    Fixed a bug where the TURN_OFF_TIME would not be calculated correctly and experience an overflow.
    Renamed incomingByte to incoming_byte to stick with a unified variable naming convention
    [StopLight_3.ino]
2021-08-29 Switched to more accurate cycle timing
    Switched the delay method from delay() to millis() to remove the code runtime from the cycle time
2021-09-26 Switched animations to time based
    Switched animations from purely being state counter dependent to
    take the cycle time into account and adapt the animation to always
    take the same amount of time and vary the steps instead.
2025-05-26 Updated scad model to add Support for the ESP32 C3 SuperMini
    Added support for ESP32 C3 SuperMini controller
    Added version of the base door that can be screwed instead of clipped
    Added parameters to Model to allow easy switching between controller versions
    [StopLight.scad]
2025-05-27 Added a new program that supports serial and web interface
    Extended the StopLight_3 to add a web server over wifi
    Moved state machine ,state definitions and pind definitions into separate files
    Added WiFi config for Access point and client modes
    Added Webserver serving a HTML page and a JSON status API
    Updated code to run on ESP32 hardware
2025-06-30 Added 3D moddel and 2D net for a folding cardboard box
    [container.scad]
